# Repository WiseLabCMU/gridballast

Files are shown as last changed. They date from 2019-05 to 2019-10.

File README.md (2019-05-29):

# GridBallast
Open Source Water Heater and Plug Load Controller

## Controller Board
This is the main board that interfaces with the peripherals.
The board integrate the following modules and features:
* ESP32
* U-Blox NEO-M8T GPS Timing Chip
* SX1276 Radio
* USB programming and debugging
* 2.4" OLED display
* 4 way navigation buttons
* Raspberry Pi connectivity
* 60Hz Frequency Monitor
* RS485 and I2C exposed interfaces
* 2000:1 current transformer input
* Amplified microphone input with phantom power
* Leak detector input

Controller Board V1 3D

[Interactive 3D View](Hardware/Controller/Info/PCBv1.stl)

## Relay, CT, and Temp Board
This is the accessory board that has two onboard high-power relays, a current transformer, and two analog inputs for temperature sensors.

Relay Board V1 3D

[Interactive 3D View](Hardware/Relay%20Board/RelayBoardV1.stl)

## CTA2045 and RS485 Board
This small accessory board holds the connector to support CTA2045 and other RS485 communications.
CTA2045 Board V1 3D

[Interactive 3D View](Hardware/CTA2045/Info/CTA2045v1.stl)

# Getting Started
1. Install the `xtensa-esp32-elf` toolchain by following the instructions here: http://esp-idf.readthedocs.io/en/latest/get-started/#setup-toolchain.
   Make sure the `xtensa-esp32-elf/bin` is added to your `PATH`.
1. Clone the repository
    ```
    $ git clone --recursive https://github.com/WiseLabCMU/gridballast.git
    ```
1. Setup the `IDF_PATH` environment variable by adding the following to your `~/.profile`:
    ```
    export IDF_PATH="<path/to/gridballast>/Support/esp-idf"
    ```
1. Build the controller module
    ```
    $ cd Source/framework
    $ make
    ```
    In the framework configuration, navigate to "Serial flasher config" and select the default serial port. This can be determined by checking which device appears in `/dev` when the controller module is connected via USB. It should start with `/dev/ttyUSB`.
    Save and exit the configuration interface.
1. Flash the controller
    ```
    $ make flash
    ```

# Runtime Configuration
The WiFi SSID and password can be configured at runtime (without recompiling and reflashing the module). Other parameters could be added as necessary.
Configuration parameters are stored in flash using the [NVS Library](http://esp-idf.readthedocs.io/en/latest/api-reference/storage/nvs_flash.html).
On initialization of the wifi module, if stored wifi configuration parameters exist, they are loaded and used to connect to wifi.
If no parameters exist, the module launches configuration mode.

In configuration mode, the module broadcasts a wifi network named "gridballast". A user can connect to the gridballast network and open
http://[module-ip]/ (by default 192.168.1.4, can be found programatically with `tcpip_adapter_get_ip_info`) in a web browser. The module will present a webpage where the SSID and password can be configured.
To exit configuration mode, the module must be rebooted.

TODO: Gridballast should also support entering configuration mode by pushing a button.
This can be done by calling `wifi_enter_config_mode()` (see `Source/framework/main/include/wifi_module.h`).

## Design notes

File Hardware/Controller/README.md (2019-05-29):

# Description
This is the main appliance controller.

# Fabrication Details
* The main fabrication files and bill of materials are in the [Project Outputs for Controller](Project%20Outputs%20for%20Controller) directory.
* The schematic, pictures, and 3D model are in the [Info](Info) directory.

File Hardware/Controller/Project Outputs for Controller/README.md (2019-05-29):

# Board Details
The overall dimensions are 133.2mm x 94mm

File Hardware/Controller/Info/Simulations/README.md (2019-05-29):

# Descriptions
This directory holds the simulation setup and results for some of the more
analog components on the Controller board.

The simulations have been performed in [LTSpice](http://www.linear.com/designtools/software/#LTspice).

# Results Preview

## Microphone and Amplifier with DC Biasing
MIC Amplifier and Bias

## Current Transformer

### Bias Only - Output Voltage
Voltage

### Bias Only - Current and Output Voltage
Current and Voltage

## 60Hz Detector

### Input with Noise
Input with Noise

### Frequency Response
Frequency Response

## Leak Detection Cable
Different Biasing Resistors

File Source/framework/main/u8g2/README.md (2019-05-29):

https://raw.githubusercontent.com/wiki/olikraus/u8g2/ref/u8g2_logo_transparent_orange.png 

U8g2: Library for monochrome displays, version 2

U8g2 is a monochrome graphics library for embedded devices. U8g2 supports controller based (for example SSD1306) monochrome OLEDs and LCDs (See the U8g2/U8x8 setup guide for a complete list of supported display controller). 
The Arduino library U8g2 can be installed from the library manager of the Arduino IDE. U8g2 also includes U8x8 library:
 * U8g2
   * Includes all graphics procedures (line/box/circle draw).
   * Supports many fonts. (Almost) no restriction on the font height.
   * Requires some memory in the microcontroller to render the display.
 * U8x8
   * Text output only (character) device.
   * Only fonts allowed with fixed size per character (8x8 pixel).
   * Writes directly to the display. No buffer in the microcontroller required.

[Setup Guide and Reference Manual](https://github.com/olikraus/u8g2/wiki)

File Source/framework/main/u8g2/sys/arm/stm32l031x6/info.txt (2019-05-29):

STM32L0	Cortex-M0/M0+
  STM32L0x1	access line
    STM32L0x1K	access line, 32 Pins (LQFP)
    STM32L0x1F	access line, 20 Pins (TSSOP20)
  STM32L0x2	USB+DAC
STM32L1	Cortex-M3
STM32L4	Cortex-M4

http://www.st.com/en/microcontrollers/stm32l031f6.html

=========

http://www.st.com/en/embedded-software/stm32cube-embedded-software.html

zip file: ~/Downloads/en.stm32cubel0.zip

this contains the lib, 
STM32Cube_FW_L0_V1.8.0/Drivers/STM32L0xx_HAL_Driver

however the lib requires a config file.
example is here:
STM32Cube_FW_L0_V1.8.0/Projects/STM32L011K4-Nucleo/Examples/GPIO/GPIO_IOToggle/Inc

startup code (.s files)
STM32Cube_FW_L0_V1.8.0/Drivers/CMSIS/Device/ST/STM32L0xx/Source/Templates/gcc

register definitions:
STM32Cube_FW_L0_V1.8.0/Drivers/CMSIS/Device/ST/STM32L0xx/Include

STM32L031xNyM
3: RAM size? 8KB
x: K=32 pins, F=20 pins
N: 4=16KB, 6=32KB
y: T=LQFP? 
M: temperature range

STM32L031F6P6	TSSOP20, 32K Flash --> available
STM32L052K8T6	LQFP32, 64K Flash, USB --> available

--> ld file for example here:

./STM32Cube_FW_L0_V1.8.0/Projects/STM32L031K6-Nucleo/Templates_LL/SW4STM32/STM32L031K6_NUCLEO/STM32L031K6Tx_FLASH.ld
however newly created and derived from nokeep.ld script

library/hal/CMSIS
  kchmviewer STM32Cube_FW_L0_V1.8.0/Drivers/STM32L0xx_HAL_Driver/STM32L073xx_User_Manual.chm
    doxygen seiten der hal treiber.... leider wie üblich nicht besonders übersichtlich

Code					Source
startup_stm32l031xx.s		STM32Cube_FW_L0_V1.8.0/Drivers/CMSIS/Device/ST/STM32L0xx/Source/Templates/gcc
	startup code, which will also call SystemInit and main()
system_stm32l0xx.c			STM32Cube_FW_L0_V1.8.0/Drivers/CMSIS/Device/ST/STM32L0xx/Source/Templates
	Contains the SystemInit() and SystemCoreClockUpdate() function.
	
system_stm32l0xx.h			STM32Cube_FW_L0_V1.8.0/Drivers/CMSIS/Device/ST/STM32L0xx/Include
	Contains the global defs for system_stm32l0xx.c. It is placed in the common/inc
	
stm32l0xx/inc				various include files copied from
      STM32Cube_FW_L0_V1.8.0/Drivers/CMSIS/Device/ST/STM32L0xx/Include/
      STM32Cube_FW_L0_V1.8.0/Drivers/CMSIS/Include/
	
Documentation
PM0223	STM32L0 Series Cortex ® -M0+ programming manual 	DM01004451.pdf	110 pages
RM0377	STM32L0x1 Reference manual						DM01008282.pdf	882 pages
  - Section 3.3.2: BOOT0 Pin (0=user, 1=bootloader)	
STM32L031x4 STM32L031x6 Datasheet						DM00140359.pdf	118 pages
AN2606	Bootloader description							CD00167594.pdf
  USART2 configuration is: 8-bits, even parity and 1 Stop bit, RX/TX on PA9/PA10 or PA2/PA3
  Die doku ist da nicht ganz eindeutig. PA10 und PA3 sind die UART2_RX pins, PA9  und PA2 die TX
AN3155	USART protocol used in the STM32™ bootloader

External tools (Ubuntu Linux)
arm-none-eabi-gcc	sudo apt install gcc-arm-none-eabi
stm32flash		sudo apt install stm32flash

stm32flash: There seems to be a problem with ch340/ch341 devices
  https://sourceforge.net/p/stm32flash/tickets/81/?limit=25&page=1#7106
  also mentioned here:
    https://sourceforge.net/p/stm32flash/wiki/Hints/
  I think this got solved in the kernel by a commit on Oct 24, 2016:
    https://github.com/torvalds/linux/commit/ba781bdf86621b71aa79a1ac0ad584f1e8aac307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
    
  modinfo ch341  -->  4.4.0-62-generic
  https://github.com/torvalds/linux/blob/v4.4/drivers/usb/serial/ch341.c --> Tag 4.4
  looks like this moved to the kernel with the 4.10 tag
  Ubuntu kernel version ermitteln: cat /proc/version
  Ubuntu 17.04 may use 4.10 and might be there at 13 Apr 2017
  ok, i will be using a cp21xx driver here...
  Conclution: Support of CH340 usb-serial converter for ubuntu linux will be there with Ubunutz 17.04

===========

steampunk

http://www.rattlebrained.org/articles/diy-pvc-train-whistle

Kupferrohre:
https://www.bengs-modellbau.de/zubehoerteile/flasche-und-fittings/
90 grad fitting
Auch nicht schlecht:
https://knupfer.info/shop/index.php/deutsch/profile-rohre/kupferrohr.html

kupferrohrflöte, obertonflöte
http://www.spiritsoundart.de/shop/obertonfloeten-aus-kupfer/
http://www.maxbrumbergflutes.eu/floeten/obertonfloeten/

englisch
https://en.wikipedia.org/wiki/Overtone_flute

Didgeridoo

===========

TODO, 17 Apr 2017
- Pullups an die buttons und die tamper pullups deaktivieren. 
  Grund: Ansonsten kann man nicht mehr per reset booten und flashen
  --> DONE (es gibt einen menü eintrag)
- Es wird ja ständig das power interface sowie RTC activiert und deaktiviert.
  Das sollte man vermutlich dauerhaft aktiviert lassen.  --> DONE

9. Mai 17
Irgendwie funktioniert das warm startup nicht. Der uC stürzt ab, wenn man
das u8x8_InitDisplay() nicht ausführt, aber warum? Was habe ich vergessen?
--> pointer fehler

todo
- load/save values to backup register --> DONE
- configuration of the standby delay value --> DONE
- display off option for standby --> DONE
- if the alarm is confirmed within the same minute, then the alarm will apear again.
    --> Fixed (checked for the is_equal flag)
- Auto detect für den externen oszillator oder quarz

============
Holzbearbeitung

redwood 15x60x60 (dictum.com)
Linse 35,5mm (astromedia.de, OM7a)
32mm Holzbohrer

Fach für 2xAAA Halterung:
Von unten mit 32mm Holzbohrer aufbohren: Achtung nicht durchbohren
Dann mit 4x 14mm Holzbohrer weiterbohren (an den Rändern des vorherigen Lochs).
Achtung nicht durchbohren

Bedienknöpfe:
Löcher mit dem Durchmesser der Knöpfe bohren (Rote Buttons hatten 12mm)

Display und uC Gehäuse:
Von unten mit 32mm Holzbohrer aufbohren: Achtung nicht durchbohren
Dann mit einem kleineren Bohrer (6mm?) entlang der Front mehrere Löcher Bohren
Auch hier: Nicht durchbohren
Mit der Stichsäge Die Bohrungen weiter aufsägen.

Display Front:
Löcher bohren, mit der Stichsäge aufbohren, dann mit der Feile quadratisch machen.

Display Abdeckung
M30: Aussendurchmesser 56mm, Innen31

Derzeit: Aussen 52, Innen 32
https://www.befestigungsfuchs.de/Befestigungstechnik/Unterlegscheiben/DIN-125/Form-A/50-Unterlegscheiben-DIN-125-Form-A-Kunststoff-Polyamid-fuer-M30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
50 Stück, 13€ + 5€ Versand

Buchescheiben 50mm, aber ca. 15€ Versand und Mindermengenzuschlag
http://www.rundstab.de/product_info.php?info=p2934_buchenscheiben-50-mm.html&no_boost=1
10 Stück 5€ + 15€ Versand

Buchescheiben 50mm, aber sortiert im set mit 35 anderen
http://www.rakuten.de/produkt/holzscheiben-35-stueck-15-5-cm-349163036.html
2 Stück für 2,60 +5€ Versand

Im Englischen heisst das wohl "flat washer"
--> Bei E-Bay bestellt Innen 33mm aussen 42mm... naja mal sehen wie das mit der Linse wird.

===============
steampunk t-shirts
--> https://www.redbubble.com
https://www.redbubble.com/people/grimdork/works/14821398-steampunk-gears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
https://www.redbubble.com/people/melaniem68/works/8073180-steampunk-play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
https://www.redbubble.com/people/amadeus-ch/works/11341440-mechanical-heart-steampunk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
https://www.redbubble.com/people/interarte/works/7300455-steampunk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
https://www.redbubble.com/people/reubsaet/works/23847501-steampunk-art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
FITTI20

---------------
todo
- uptime counter	--> done
- bessere voltanzeige --> nicht umgesetzt, aber optional
- winterzeit: Muss direkt auf der hardware gemacht werden, alles andere ist zu kompliziert

---------------

extras
obertonflöte: schwierig, vor allem wegen der luft

fliehkraftregler (governor): kann man wohl praktisch nicht kaufen
http://www.hilltop-cottage.info/blogs/adam/model-watt-governor-cad-plans-and-construction-notes/
http://www.stuartmodels.com/products/fittings--tools---accessories/governor---spring-belt  ... teuer
Alles zu teuer.
Glocke mit servo dran...

---------------

A) short description of the STM32L0 RTC
- date/time register
- CR register with special DST features (BKP, SUB1H and ADD1H flags)
- two step write protection:
    PWR->CR |= PWR_CR_DBP;
    
    RTC->WPR = 0x0ca;					/* disable RTC write protection */
    RTC->WPR = 0x053;
  B) algorithm
     - basic idea
    - special case for winter time change (double hour)
  C) Date calculation
  D) Code

---------------
Bauteile Steampunk Clock mit MKR Zero

Gold-Spr�hlack

Kupferrohre 3x Durchmesser 12mm, L�nge 40mm, Meterware Baumarkt
Kupferrohre 2x L-St�ck, 12mm, Baumarkt
Steckernetzteil 5V, 2.1mm Hohlstecker (z.B. Reichelt SNT 1000 5V)
Einbaukupplung, 2.0mm Stift (z.B. Reichelt LUM NEBJ 21C)
Buzzer, Durchmesser 10mm
--> Achtung: Den CAD Plan noch ändern.

---------------
Bugs

Man scheint die zeit nicht immer vorzeitig ausschalten zu können. Warum?
Erneutes eingeben der alarmzeit behebt das problem.
Manchmal erscheit die nächste zeit gar nicht im display. Auch hier
behebt das erneute eingeben der alarmzeit das problem.
Es sieht so aus: man schaltet die zeit vorzeitig ab, dann erscheint das menü
für den übernächsten tag nicht (für den folgenden tag hatte man es ja abgeschaltet).

17. Sep 2017: einen bug in uint32_t get_u32_by_alarm_data(gui_alarm_t *alarm) behoben

---------------
MKR Zero

Processor: SAMD21G18

---------------
Ausgabe, ob gerade winter oder sommerzeit aktiv ist.

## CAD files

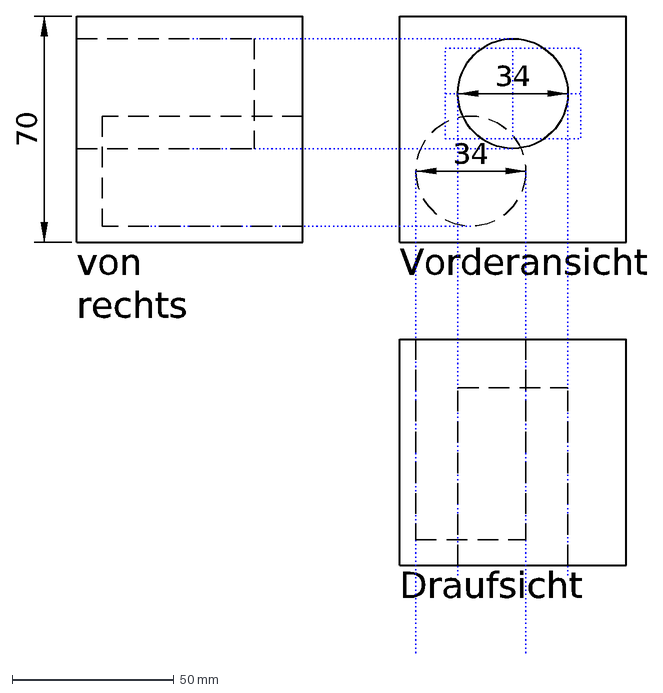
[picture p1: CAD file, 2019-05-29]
Source/framework/main/u8g2/sys/arm/stm32l031x6/clock_cube.dxf
Draufsicht
Vorderansicht
von rechts
70
34

Source/framework/main/u8g2/sys/arm/stm32l031x6/clock_2.dxf
65
Draufsicht
Vorderansicht
von unten
von rechts
von links
14
30
32
35
75
55
10
12
16
11
22
34
28
29
18
93
19
43
15
68
60
57
150
Holzbohrer: 2.5, 8, 10, 12, 16, 32mm
8
7
6
2.5mm

Source/framework/main/u8g2/sys/arm/stm32l031x6/clock.dxf
65
32
28
16
Draufsicht
Vorderansicht
von unten
von rechts
von links
14
6
45
60
30
20
8
35
75
55
10
12

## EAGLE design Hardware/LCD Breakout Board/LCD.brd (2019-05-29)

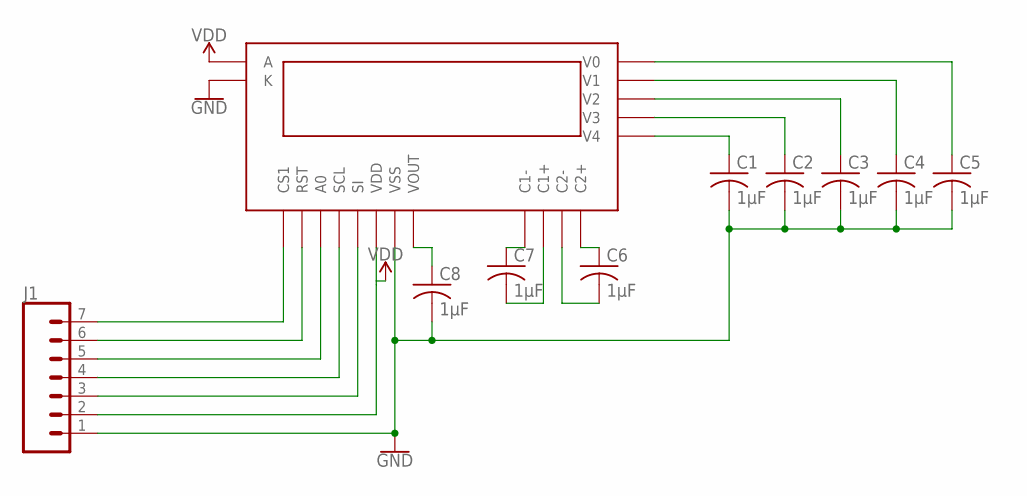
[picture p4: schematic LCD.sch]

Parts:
C1, C2, C3, C4, C5, C6, C7, C8: 1µF; C1206
J1: CONN_07; 1X07
U$1: LCD-NHD; NHD-C12832A1Z

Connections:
A0: J1.5, U$1.A0
CS1: J1.7, U$1.CS1
GND: C1.2, C2.2, C3.2, C4.2, C5.2, C8.2, J1.1, U$1.K, U$1.VSS
unnamed: C5.1, U$1.V0
unnamed: C4.1, U$1.V1
unnamed: C3.1, U$1.V2
unnamed: C2.1, U$1.V3
unnamed: C1.1, U$1.V4
unnamed: C7.1, U$1.C1-
unnamed: C7.2, U$1.C1+
unnamed: C6.1, U$1.C2+
unnamed: C6.2, U$1.C2-
RST: J1.6, U$1.RES (RST)
SCL: J1.4, U$1.SCL
SI: J1.3, U$1.SI
VDD: J1.2, U$1.A, U$1.VDD
VOUT: C8.1, U$1.VOUT

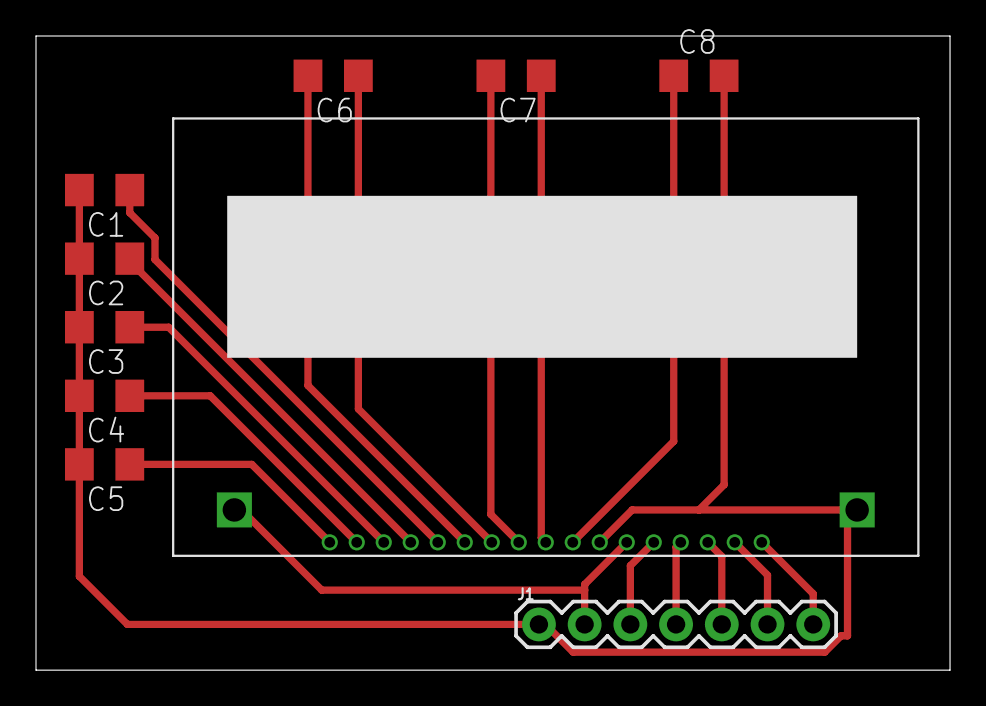
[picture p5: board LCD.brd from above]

Board: 2 copper layers, 50.8 x 35.2 mm, 10 parts (0 on the bottom side), 17 nets.

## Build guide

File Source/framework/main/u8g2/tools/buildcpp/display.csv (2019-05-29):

# 1. device name
# 2. pinset
# 3. constructor name w/o prefix
u8x8_d_ssd1306_128x64_noname | 4WSWSPI | SSD1306_128X64_4W_SW_SPI
u8x8_d_ssd1306_128x64_noname | 4WHWSPI | SSD1306_128X64_4W_HW_SPI
u8x8_d_ssd1306_128x64_noname | 3WSWSPI | SSD1306_128X64_3W_SW_SPI
u8x8_d_ssd1306_128x64_noname | SSDSWI2C | SSD1306_128X64_SW_I2C
u8x8_d_ssd1306_128x64_noname | 6800 | SSD1306_128X64_6800
u8x8_d_ssd1306_128x64_noname | 8080 | SSD1306_128X64_8080

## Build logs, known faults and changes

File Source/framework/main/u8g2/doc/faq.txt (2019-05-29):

Sections
- Wiring... Interconnect, pin/label names
- Displays... Display support, display problems
- U8g2... Setup, compilation, usage, fonts

Wiring

Q: Why does my xxx_SW_I2C() device not work with my other I2C devices?
A: SW_I2C emulates I2C with digitalWrite(), which will have a conflict with other
I2C devices at the same pins. There are two options: (A) use xxx_HW_I2C() or 
(B) use different pins with xxx_SW_I2C()

Q: My display has a pin labled as "A0" (or "RS"). How to connect this pin?
A: There are different names for the "data/command" pin. In U8g2 only the name
"dc" is used. On the display side it might be also called "A0", "RS", "CD".
See also the next question.

Q: My display has pins labled as "D0" and "D1". What is the interface and how 
to connect these pins?
A: This is probably a SSD1306 OLED. The meaning of the D0 and D1 pin depends
on the configuration of the SSD1306. D0 is the clock line and D1 is the data line.

Q: For HW SPI no pin numbers are required in the constructor. But which are
the pin numbers for wiring?
A: This depends on your board. For some official boards, this is listed here:
https://www.arduino.cc/en/Reference/SPI
You need to connect MOSI (data) and SCK (clock) pins of your board with the
corresponding pins with your display.
All U8g2 software emulated SPI constructors look like this:
U8G2_..._4W_SW_SPI u8g2(U8G2_R0, clock, data, cs, dc, reset);
All U8g2 hardware SPI constructors look like this:
U8G2_..._4W_SW_SPI u8g2(U8G2_R0, cs, dc, reset);

Q: For HW I2C no pin numbers are required in the constructor. But which are
the pin numbers for wiring?
A: See same question for SPI. For some boards, the pins are listed here:
https://www.arduino.cc/en/Reference/Wire
All U8g2 software emulated I2C constructors look like this:
U8G2_..._SW_I2C u8g2(U8G2_R0, clock, data, reset);
All U8g2 hardware I2C constructors look like this:
U8G2_..._HW_I2C u8g2(U8G2_R0, reset);
Note: The HW_I2C allows to more arguments for hardware pin number remapping.
However, this is only supported on the ESP8266.

Q: The pin names on my display do not fit to the pin names of U8g2.
A: Yes, each datasheet/product/controller has different names. There 
is a mapping table on the wiki for this:
https://github.com/olikraus/u8g2/wiki/u8g2setupcpp#wiring

Q: What is wrong with connecting Reset (RES) of my display with the  Reset of my 
Arduino Board?
A:
- Both are inputs. It does not make sense to connect two inputs
- Both pins have completly different functions: The reset of your board will reset
the Arduino board, the reset of the display will reset the display. 
Please connect the reset input of the display with a normal GPIO pin of your board.

Q: Shell I connect CS (chip select) with the SS output of the Arduino board?
A: In general this is required neither for hardware or software SPI.

Q: My board has a MOSI and a SCK output. Do i need to connect this to the
clock and data pins of my display?
A: "Yes" if you want to use hardware SPI (u8g2 constructors ending in _HW_SPI).
You can use any pins with the software emulated SPI of u8g2 (constructors ending
in _SW_SPI). Howver in general it is better to use hardware SPI to get a better
performance of your display.

Q: How to wire ST7920 display in 8080 mode?
A:
- See also https://github.com/olikraus/u8g2/wiki/gallery#26-nov-2016-st7920-128x64-lcd-in-8080-parallel-mode
- Connect the RW (SID) input of your ST7920 display to ground.
- In the u8g2 constructor, use U8X8_PIN_NONE for "cs" signal
- The "dc" pin is called "RS" in the ST7920 documentation.
- See also issue #90: https://github.com/olikraus/u8g2/issues/90

Displays

Q: There is an x-offset on my SSD1306 128x64 OLED. 
A: This is not a SSD1306 OLED, instead use the SH1106 constructor.

Q: A T6963 misses columns on the display/has garbled output.
A: Ensure that the T6963 operates in 8x8 mode: 
If the display module has two font select (FSx) pins, connect both to GND
If the display module has one font select (FS) pin, connect it to GND

Q: My T6963 has a RD input. How shell this be connected?
A: The RD input for any 8080 interface has to be connected to power supply (5V or 3.3V, 
depending on the display)

Q: My T6963 was working with u8glib, but it does not work with U8g2
A: The sequence of argument has changed from cs, a0, wr to wr, cs, a0:
U8GLIB_T6963_240X128 u8g(d0, d1, d2, d3, d4, d5, d6, d7, cs, dc, wr, rd, reset); 
U8G2_T6963_240X128_1_8080 u8g2(U8G2_R0, d0, d1, d2, d3, d4, d5, d6, d7, wr, cs, dc, reset); 

Q: My controller/interface combination is not listed in the examples.
A: Yes, the complete list is here:
https://github.com/olikraus/u8g2/wiki/u8g2setupcpp

Q: My display controller is listed, but the display dimension is not supported.
A: Raise an issue in the u8g2 tracker "https://github.com/olikraus/u8g2/issues"

Q: My controller is not listed, What can I do?
A: First check whether this controller is compatible to one of the supported 
controller:
Supported: ST7565, Compatible: NT7534, UC1701, SED1565, S1D15605, S6B0723, SPLC502
Supported: SED1330, Compatible:  SED1335, RA8835, S1D3305 
Supported: LC7981, Compatible:  NT7086, (maybe also: HD61830)
This table just reflects my current knowledge. It is not tested and may not be true at all.
Raise an issue in the u8g2 issue tracker, If your controller for a monochrome display is not listed.
A more detailed discussion of some controllers is listed in "controller_cmds.txt"

U8g2

Q: How to install u8g2 for Arduino?
A: The latest stable version of U8g2 is available as Arduino Library in the 
"Manage Libraries..." browser. See also here: https://github.com/olikraus/u8g2/wiki/u8g2install
The latest development version is available for download here:
https://github.com/olikraus/U8g2_Arduino/archive/master.zip
In the Arduino IDE use the Sketch>Include Library>Add .ZIP Library... menu to 
import the u8g2 zip library.

Q: There is a compilation error with I2C/SPI library used by U8g2.
A: U8g2 expects standard Arduino lWire and SPI libraries. However some
none-Arduino Boards did not implement the full set of library functions.
Examples are the missing setClock() or missing beginTransaction() functions.
This is an issue with your board support library and not an issue of U8g2.
Workaround:
1. Disable (comment) U8X8_HAVE_HW_SPI and/or U8X8_HAVE_HW_I2C in u8x8.h
2. Use SW SPI/SW I2C U8g2 constructors

Q: What is the meaning of the F/1/2 in the U8g2 constructor name?
A: "F" means full buffer mode. The entire display is rendered in RAM. Use
"sendBuffer" to transfer this RAM buffer to the display. "1"  and "2" constructors
will store one or two pages of the display in RAM only. Use the firstPage/nextPage 
loop to create the image for the display.

Q: What is the meaning of "SW"/"HW" in the U8g2 constructor name?
A: "SW" means, that the protocol is emulated by software. For example 
the SW_I2C will not use the I2C subsystem of your board. The "HW" constructor
will use the hardware subsystem on your uC. For an Arduino board, HW_I2C will
call the Wire library for hardware accelerated I2C communication. "HW"
constructors are much faster, but maybe debugging and setup is more 
easier with a "SW" constructor.

Q: Why does the hardware I2C accept clock and data pins?
The hardware I2C constructor looks like this:
U8G2_<display>_HW_I2C(rotation, [reset [, clock, data]])
This means there are three options to use this constructor:
1. U8G2_<display>_HW_I2C(rotation)
2. U8G2_<display>_HW_I2C(rotation, reset)
3. U8G2_<display>_HW_I2C(rotation, reset, clock, data)
Hardware I2C usually is possible only with fixed pins. This means, the first or 
second form of the constructor must be used. As of today only the ESP8266 
support pin remapping. In such a case, also the third form can be used.

Q: How to activate 16 Bit mode?
A: Search for the line
//#define U8G2_16BIT
in "u8g2.h". Uncomment this line:
#define U8G2_16BIT
The file "u8g2.h" is located in "/libraries/U8g2_Arduino/src/clib" inside your default
sketch folder.

Q: U8g2 requires a lot of memory. How to reduce this?
- Limit the font size. If possible avoid "f" fonts, instead use "r" fonts
- If the I2C interface is not required, then uncomment #define U8X8_HAVE_HW_I2C in U8x8lib.h
  (Background: Due to a problem in Wire.h, the I2C Arduino lib is always included)

Q: U8g2 output is corrupted. What are possible causes?
- Do not change the output inside the firstPage/nextPage loop: 
Do *not* call digitalRead/analogRead inside the firstPage/nextPage loop.
Read any sensor values into a variable *before* firstPage() and use the 
variable value inside the loop.
- If the output includes unicode chars, use the UTF8 procedures.

Q: How can I generate my own font.
A: The font must be available in bdf file format. Then use bdfconv to generate
the font data. The font data can be pasted into an existing file of your project.

Q: Which commandline options are required for bdfconv?
A: "bdfconv -f 1 -m '32-255' -n fontname -o myfont.c myfont.bdf"
"-f 1" generates a u8g2 font.
"-m '32-255'" selects unicode 32 to 255. On Windows, please use double quotes: -m "32-255"
"-n fontname": This is the name of the font in C/C++/Ino files.
"-o myfont.c": The font array will be stored in this file.
"myfont.bdf": The input file with the font data (bdf format).

Q: Where do I find bdfconv?
A: A Windows executable is available here:
https://github.com/olikraus/u8g2/tree/master/tools/font/bdfconv
Use the Makefile in this directory to create a Linux binary.

Q: How can I use multiple SPI Displays?
A: For each additional display, separate CS (Chip select) and RST (Reset) lines are required. 

```C++
// Setup display1 and display2
U8G2_SSD1306_128X64_NONAME_F_4W_SW_SPI display1(U8G2_R0, /*CLK*/ 18, /*MOSI*/ 23, /*CS*/ 16,
                                                /*DC*/ 17, /*RS*/ 4);
U8G2_SSD1306_128X64_NONAME_F_4W_SW_SPI display2(U8G2_R0, /*CLK*/ 18, /*MOSI*/ 23, /*CS*/ 15,
                                            /*DC*/ 17, /*RS*/ 4);    
```
Ensure that the buffer is sent after printing with each display as follows.

```C++
    display1.begin();
    display2.begin();
    
    display1.setCursor(64, 32);
    display1.print("DISPLAY 1");
    display1.sendBuffer();
    
    display2.setCursor(64, 32);
    display2.print("DISPLAY 2");
    display2.sendBuffer();
```

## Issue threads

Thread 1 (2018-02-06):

I2C Fix

linux4life798, 2018-02-06:
Proposed solution:
* Move I2C lines from <IO34 and IO35> to <IO25 and IO26>
* Move GPS_PPS and 60Hz from <IO25 and IO26> and <IO34 and IO35>

linux4life798, 2018-02-13:
Done

Closed 2018-02-13.

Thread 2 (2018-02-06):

Add 5V to RJ45

linux4life798, 2018-02-06:
Should add 5V such that it does not interfere with the Sparkfun RS485 adapter.

https://www.sparkfun.com/products/10124

linux4life798, 2018-02-07:
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

Sparkfun seems to leave pins 1, 2, 3, and 6 open for anything.

Maybe we should then send 5V down pins 2 and 3, and use pin 1 for 60Hz.

linux4life798, 2018-02-13:
Done

Closed 2018-02-13.

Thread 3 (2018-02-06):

Add 60Hz to RJ45

linux4life798, 2018-02-06:
In a manner that doesn't interfere with Sparkfun RS485 adapter.

linux4life798, 2018-02-13:
Done

Closed 2018-02-13.

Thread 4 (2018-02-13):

Q1 Connections are Incorrect in Schematic

aperley, 2018-02-13:
`MCU_BOOT` is connected to collector of Q1B, but it should be connected to emitter.

V1.1 schematic:
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

Reference Design:
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

linux4life798, 2018-02-13:
Yep, that looks like an issue.

How did the other board still program?

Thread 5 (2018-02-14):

LCD Connector is Mirrored

aperley, 2018-02-14:
The LCD ribbon cable connector is wired the wrong way around. The exposed end of the ribbon cable should be inserted into the connector facing up, but the wiring of the pins requires that it be inserted facing down. This does not make a great connection and requires that the locking plastic piece be inserted above the ribbon cable instead of below it.

linux4life798, 2018-06-18:
We now use the connector found [here](https://www.digikey.com/products/en?keywords=HFY031CT-ND).

@anhluong Added the footprint to the PCB.

Closed 2018-06-18.

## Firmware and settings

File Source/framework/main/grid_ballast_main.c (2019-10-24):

/**
 * @file grid_ballast_main.c
 *
 * @brief main function that starts up the grid ballast system

 * @author Rohit Gaarg (rohitg1)
 * @author Vikram Shanker (vshanker@cmu.edu)
 */

#include <stdio.h>
#include <string.h> /* memset */
#include "rwlock.h"

#include "controller_module.h"
#include "esp_system.h"
#include "freertos/FreeRTOS.h"
#include "freertos/task.h"
#include "nvs_flash.h"
#include "sensing_module.h"

#include "Ada_MCP.h" // IO Expander Library
#include "generic_rw_i2c.h"  // generic I2C read/write functions

#include "system_state.h"
#include "wifi_module.h"
#include "lcd_module.h"
#include "frq_module.h"
#include "rs_485_module.h"
#include "button.h"
#include "controller_module.h"
#include "ct_module.h"
#include "driver/timer.h"
#include "util.h"
#include "driver/adc.h"
#include "esp_adc_cal.h"
#include "wifi_adc.h"
#include "lora_module.h"

bool State = true;


#define ESP_INTR_FLAG_DEFAULT 0

system_state_t gb_system_state;
rwlock_t system_state_lock;
rwlock_t i2c_lock;


#define PIN_MCP_RESET 2                   // I/O expander reset pin

#define PIN_SDA 25                        /*i2c pins */
#define PIN_SCL 26                       
#define I2C_MASTER_FREQ_HZ     100000     /* I2C master clock frequency */

#define LEVEL_HIGH 1
#define LEVEL_LOW 0


/**
 * @brief initialization task that starts all other threads
 *
 * @param pv_parameters - parameters for task being created (should be NULL)
 *
 * @return void
 */
void init_task( void *pv_parameters ) {

    gpio_install_isr_service(ESP_INTR_FLAG_DEFAULT);
    
    // temporary snippet to change thermostat set point
    rwlock_writer_lock(&system_state_lock);
    get_system_state(&gb_system_state);
    gb_system_state.set_point = 100;
    gb_system_state.threshold_overfrq = 60.01;
    gb_system_state.threshold_underfrq = 59.99;
    gb_system_state.input_mode = 0;
	gb_system_state.lcd_display_mode = DISPLAY_INFO;
    set_system_state(&gb_system_state);
    rwlock_writer_unlock(&system_state_lock);
        
    wifi_init_task();
    //sensing_init_task();

    controller_init_task();

    printf("Initializing frq\n");
    frq_init_task();
    printf("Initializing rs485\n");
    
    button_init_task();
    
    printf("Initializing lcd\n");
    lcd_init_task();
    //wifi_adc_init();  
    // lora_init();     
    //rs485_init_task();
    //ct_init_task();
    printf("Initialization done\n");    
    //vTaskDelay(500/portTICK_PERIOD_MS);
    while(1);

}
    


/**
 * @brief main function that starts the initialization task
 *
 * @return void
 */



void app_main( void ) 
{
    
    nvs_flash_init();
    /* initialize gb_system_state to 0's */
    memset(&gb_system_state, 0, sizeof(gb_system_state));
    rwlock_init(&system_state_lock);
    rwlock_init(&i2c_lock);
    printf("Intializing GridBallast system...\n");


    xTaskCreate( &init_task, "init_task", 4096, NULL, 1, NULL);
    

    gpio_pad_select_gpio(PIN_MCP_RESET);
    gpio_set_direction(PIN_MCP_RESET, GPIO_MODE_OUTPUT);
    gpio_set_level(PIN_MCP_RESET, 1);
  // // rwlock_writer_lock(&i2c_lock);
   generic_i2c_master_init (I2C_NUM_1, PIN_SCL, PIN_SDA, I2C_MASTER_FREQ_HZ);

    begin(0);

    pinMode(8,GPIO_MODE_OUTPUT);       // test o/p

    digitalWrite(8,0);

    vTaskDelay(0.05 / portTICK_PERIOD_MS);

    digitalWrite(8,1);
	
 //Characterize ADC at particular atten
    // esp_adc_cal_characteristics_t *adc_chars = calloc(1, sizeof(esp_adc_cal_characteristics_t));
    // esp_adc_cal_value_t val_type = esp_adc_cal_characterize(ADC_UNIT_1, ADC_ATTEN_DB_11, ADC_WIDTH_BIT_9, 1100, adc_chars);
    // //Check type of calibration value used to characterize ADC
    // if (val_type == ESP_ADC_CAL_VAL_EFUSE_VREF) {
    //     printf("eFuse Vref");
    // } else if (val_type == ESP_ADC_CAL_VAL_EFUSE_TP) {
    //     printf("Two Point");
    // } else {
    //     printf("Default");
    // }

    // while(1)
    // {

    // adc2_vref_to_gpio(26);

    // uint32_t reading =  adc1_get_raw(ADC1_CHANNEL_0);
    // uint32_t voltage = esp_adc_cal_raw_to_voltage(reading, adc_chars);

    // printf("%u\n",voltage);

    // vTaskDelay(2000 / portTICK_PERIOD_MS);
 

//}

}

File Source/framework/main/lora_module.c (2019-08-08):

#include "driver/spi_common.h"
#include "driver/spi_master.h"
#include "lora_module.h"
#include <string.h>
#include "esp_err.h"
#include "freertos/task.h"
#include "Ada_MCP.h" 
#include "driver/gpio.h"


spi_bus_config_t spi_bus_config;
spi_device_interface_config_t spi_device_config;
static spi_device_handle_t handle_spi;      // SPI handle.

void spi_bus_configure() {
    spi_bus_config.mosi_io_num = 23;
    spi_bus_config.miso_io_num = 19;
    spi_bus_config.sclk_io_num = 18;
    spi_bus_config.quadwp_io_num = -1;
    spi_bus_config.quadhd_io_num = -1;
    spi_bus_config.max_transfer_sz = 4096;
}

void spi_device_configure() {
    spi_device_config.address_bits     = 0;
    spi_device_config.command_bits     = 0;
    spi_device_config.dummy_bits       = 0;
    spi_device_config.mode             = 0;
    spi_device_config.duty_cycle_pos   = 0;
    spi_device_config.cs_ena_posttrans = 0;
    spi_device_config.cs_ena_pretrans  = 0;
    spi_device_config.clock_speed_hz   = 10000;
    spi_device_config.spics_io_num     = 21;
    spi_device_config.flags            = 0;
    spi_device_config.queue_size       = 200;
    spi_device_config.pre_cb           = NULL;
    spi_device_config.post_cb          = NULL;
}

/*
 */
void rfm95_send_data (uint8_t data) {
    esp_err_t ret;
    uint8_t tx_data = data;
    spi_transaction_t trans_desc;
    memset(&trans_desc, 0, sizeof(trans_desc)); 
    trans_desc.tx_buffer = (void *)(&tx_data);
    trans_desc.length = BYTE_SIZE * sizeof(uint8_t);
    trans_desc.user = (void *)0;
    ret = spi_device_transmit(handle_spi, &trans_desc);
    assert(ret == ESP_OK);
}

void rfm95_receive_data(uint8_t *rx_data) {
    esp_err_t ret;
    spi_transaction_t trans_desc;
    memset(&trans_desc, 0, sizeof(trans_desc)); 
    trans_desc.rx_buffer = rx_data;
    trans_desc.length = BYTE_SIZE * sizeof(uint8_t);;
    trans_desc.user = (void *)1;
    ret = spi_device_transmit(handle_spi, &trans_desc);
    assert( ret == ESP_OK );
}

void rfm95_read_register(uint8_t reg, uint8_t *data) {
    uint8_t read_register = reg & 0x7f;
    gpio_set_level(HOPE_RF_SLAVE_SELECT_PIN, 0);
    rfm95_send_data(read_register);
    rfm95_receive_data(data);
    gpio_set_level(HOPE_RF_SLAVE_SELECT_PIN, 1);
    printf("reg %x data %x\n", reg, *data);
}

void rfm95_write_register(uint8_t reg, const uint8_t val) {
    uint8_t write_register = reg | 0x80;
    gpio_set_level(HOPE_RF_SLAVE_SELECT_PIN, 0);
    rfm95_send_data(write_register);
    rfm95_send_data(val);
    gpio_set_level(HOPE_RF_SLAVE_SELECT_PIN, 1);
    /* uint8_t check;
    rfm95_read_register(reg, &check);
    printf("reg %x val %x check %x\n", reg, val, check);
    assert(check == val);*/
}

/*
  Puts the Hope RF Lora module to sleep
  Input - none
  Return - none
 */
void rfm95_sleep() {
    //send the register address and data to put it to sleep
    uint8_t sleep;
    rfm95_read_register(REG_OP_MODE, &sleep);
    sleep = (sleep & RF_OPMODE_SLEEP) | MODE_SLEEP;
    rfm95_write_register(REG_OP_MODE, sleep);
}

void rfm95_idle() {
    uint8_t standby;
    rfm95_read_register(REG_OP_MODE, &standby);
    standby = (standby & RF_OPMODE_SLEEP) | MODE_STDBY;
    rfm95_write_register(REG_OP_MODE, standby);
}

void rfm95_tx() {
    uint8_t tx;
    rfm95_read_register(REG_OP_MODE, &tx);
    tx = (tx & RF_OPMODE_SLEEP) | MODE_TX;
    rfm95_write_register(REG_OP_MODE, tx);
}
uint8_t get_pa_select(uint64_t channel) {
    //NOTE - this may have to be revisited in case things dont work
    if (channel > RF_MID_BAND_THRESH) {
        return RF_PACONFIG_PASELECT_PABOOST;
    }
    else {
        return RF_PACONFIG_PASELECT_RFO;
    }
}

void rfm95_set_tx_power(int8_t power) {
    uint8_t pa_config = 0;
    uint8_t pa_dac = 0;
    rfm95_read_register(REG_PA_CONFIG, &pa_config);
    rfm95_read_register(REG_PA_DAC, &pa_dac);
    pa_config = ( pa_config & RF_PACONFIG_PASELECT_MASK ) | get_pa_select(RF_FREQUENCY);
    pa_config = ( pa_config & RF_PACONFIG_MAX_POWER_MASK ) | 0x70;

    if ((pa_config & RF_PACONFIG_PASELECT_PABOOST ) == RF_PACONFIG_PASELECT_PABOOST ) {
        if( power > 17 ) {
            pa_dac = ( pa_dac & RF_PADAC_20DBM_MASK ) | RF_PADAC_20DBM_ON;
        }
        else {
            pa_dac = ( pa_dac & RF_PADAC_20DBM_MASK ) | RF_PADAC_20DBM_OFF;
        }
        if( ( pa_dac & RF_PADAC_20DBM_ON ) == RF_PADAC_20DBM_ON ) {
            if( power < 5 ) {
                power = 5;
            }
            if( power > 20 ) {
                power = 20; 
            }
            pa_config = ( pa_config & RF_PACONFIG_OUTPUTPOWER_MASK ) | ( uint8_t )( ( uint16_t )( power - 5 ) & 0x0F );
        }
        else {
            if( power < 2 ) {
                power = 2;
            }
            if( power > 17 ) {
                power = 17;
            }
            pa_config = ( pa_config & RF_PACONFIG_OUTPUTPOWER_MASK ) | ( uint8_t )( ( uint16_t )( power - 2 ) & 0x0F );
        }
    }
    else {
        if( power < -1 ) {
            power = -1;
        }
        if( power > 14 ) {
            power = 14;
        }
        pa_config = ( pa_config & RF_PACONFIG_OUTPUTPOWER_MASK ) | ( uint8_t )( ( uint16_t )( power + 1 ) & 0x0F );
    }
    rfm95_write_register( REG_PA_CONFIG, pa_config );
    rfm95_write_register( REG_PA_DAC, pa_dac );

}

bool is_transmitting() {
    uint8_t rx_data;
    rfm95_read_register(REG_IRQ_FLAGS, &rx_data);
    if (rx_data & IRQ_TX_DONE_MASK) {
        return true;
    }
    rfm95_read_register(REG_IRQ_FLAGS, &rx_data);
    if (rx_data & IRQ_TX_DONE_MASK) {
        // clear IRQs
        rfm95_write_register(REG_IRQ_FLAGS, IRQ_TX_DONE_MASK);
    }
    return false;
}

void begin_packet() {
    uint8_t rx_data = 0;
    if (is_transmitting()) {
        //allow other tasks to run here 
        return;
    }
    rfm95_idle();
    //we'll set it to the explicit header mode
    rfm95_read_register(REG_MODEM_CONFIG_1, &rx_data);
    rx_data &= 0xfe;
    rfm95_write_register(REG_MODEM_CONFIG_1, rx_data);

    // reset FIFO address and payload length
    rfm95_write_register(REG_FIFO_ADDR_PTR, 0);
    rfm95_write_register(REG_PAYLOAD_LENGTH, 0);

}

void end_packet() {
    uint8_t rx_data = 0;
    // put in TX mode
    rfm95_write_register(REG_OP_MODE, MODE_LONG_RANGE_MODE | MODE_TX);
    //not sure if async is needed
    vTaskDelay(50 / portTICK_PERIOD_MS);
    while (1) {
        rfm95_read_register(REG_IRQ_FLAGS, &rx_data);
        if (rx_data & IRQ_TX_DONE_MASK) {
            break;
        }
        else {
            vTaskDelay(500/portTICK_PERIOD_MS);
            rx_data = 0;
        }
    }
    writeRegister(REG_IRQ_FLAGS, IRQ_TX_DONE_MASK);
}
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

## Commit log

2019-05-22 Indexing for GPIO4,5,6,7 fixed for gridballast toggling
    [Ada_MCP.h]
2019-05-29 SoftAP working over wifi. Posting works partially but there are problems receiving
    [CTA2045v1.GBL, CTA2045v1.GBS, CTA2045v1.GKO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]
2019-05-29 fixed the wifi_module line 375
    [wifi_module.c]
2019-05-29 remove printf
2019-06-05 Edits made to fix both relays opening bug
    [wifi_module.c]
2019-06-06 Commenting out this to avoid errors
    [lora_module.c]
2019-06-06 Buttons working well. LCD screen not cleaned up yet
2019-06-06 Buttons working well. Screen fixed. Minor issue with LCD display in Input Mode. 'p' in "OpenChirp" is still outside the screen
    [lcd_module.c]
2019-06-07 Buttons working. LCD screen cleaned up. On the fly switch to wifi config mode supported. 2 buttons used as screen navigator and 2 buttons used to increment and decrement values. 4 LCD screens display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
2019-06-12 Commented out begin(0) to fix error with shutting of relays temporarily
    [button.c]
2019-06-17 Enabled the Current transformer module that uses ADC-1
2019-06-20 Buttons slowed down, base for fixing send/recieve logic built...needs more work
    [button.c, wifi_module.c]
2019-06-25 manual mode and full auto mode trigger appropriatley, still errors when sending temp_Set value when changed on device itself. check button.c, wifi_module.c, wifi_module.h
    [button.c, wifi_module.c]
2019-06-26 Priority for wifi sending and controller_module.c fixed, made equal, send_temp_wrapper fixed so it sends system setpoint, not pointer
    [wifi_module.c]
2019-07-03 Wifi and ADC multiplexing implemented
    1) Wifi and ADC able to multiplex
    2) ADC2 still not working
    3) Screen issue fixed
    [ct_module.c, grid_ballast_main.c, lcd_module.c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]
2019-07-08 Print Messages removed
2019-08-07 print statements

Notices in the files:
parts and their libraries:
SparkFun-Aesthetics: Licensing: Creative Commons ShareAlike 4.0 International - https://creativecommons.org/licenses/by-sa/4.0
